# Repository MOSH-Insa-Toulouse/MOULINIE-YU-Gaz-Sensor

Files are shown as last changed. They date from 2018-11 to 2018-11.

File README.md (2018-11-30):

# Connected gas sensor / LoRa TTN
Project 5th ISS - MOSH - TP Gas Sensor
Authors: MOULINIÉ Dorian & YU Juan from INSA Toulouse - 5 ISS

# Description

This main goal of this project is to build a connected nanoparticle gas sensor to monitor the concentration of gas.

For this, we used an Arduino UNO and RN2483 LoRa chip to send data on the The Things Network.

We used Kicad for building this shield. Because it is an Open Source Electronics Design Automation Suite. We are able to use  the Schematic Capture and the PCB Layout along with the 3D Viewer in it. They can help us have a more specific view of our shield.

# Content

a KiCad project manage file

KiCad Schematic files

KiCad PCB Files: A shield for the gas sensor and the LoRa Module to plug in an Arduino Uno

KiCad Libraries

Pictures of the components

Readme file

## Overview

This shield is composed of:

 - a LoRa Module (RN2483) as transceiver
 - a Gas sensor
 - an amplifier (LTC1050)
 - a Groove connector for future calibration of the Gas Sensor

First, we created the project with an arduino UNO

Then, we created a library symbol for LTC 1050

Afterwards, we created the following circuit :
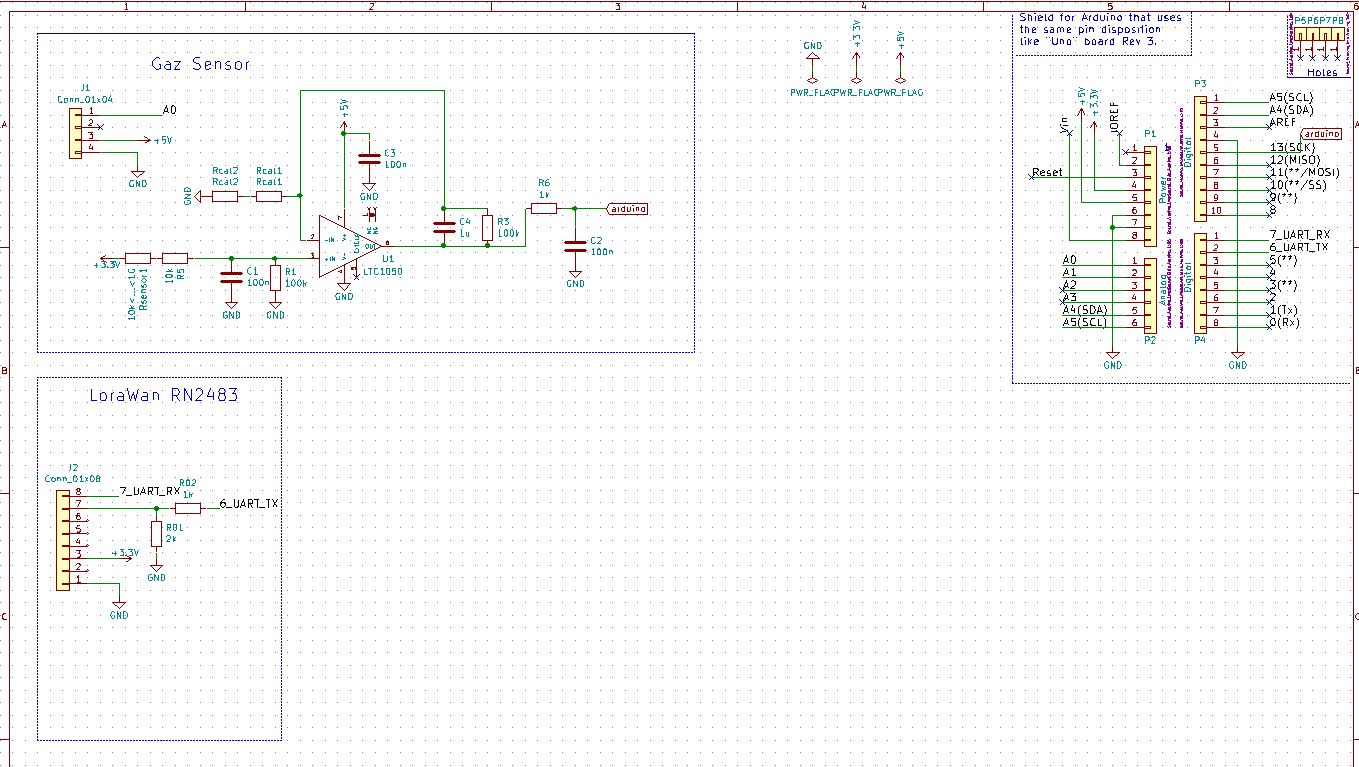
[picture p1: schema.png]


### PCB

In order to add the gas sensor to the board, we first created an new footprint. 

After we had all the components prepared, we started to do the routage.
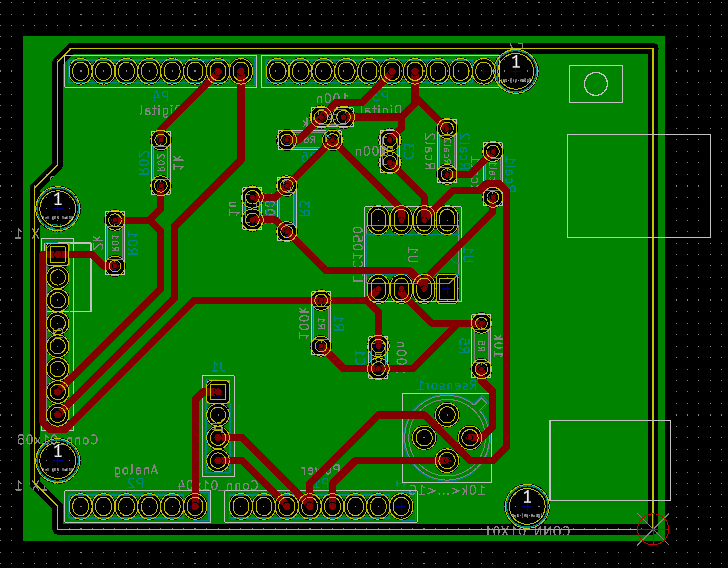
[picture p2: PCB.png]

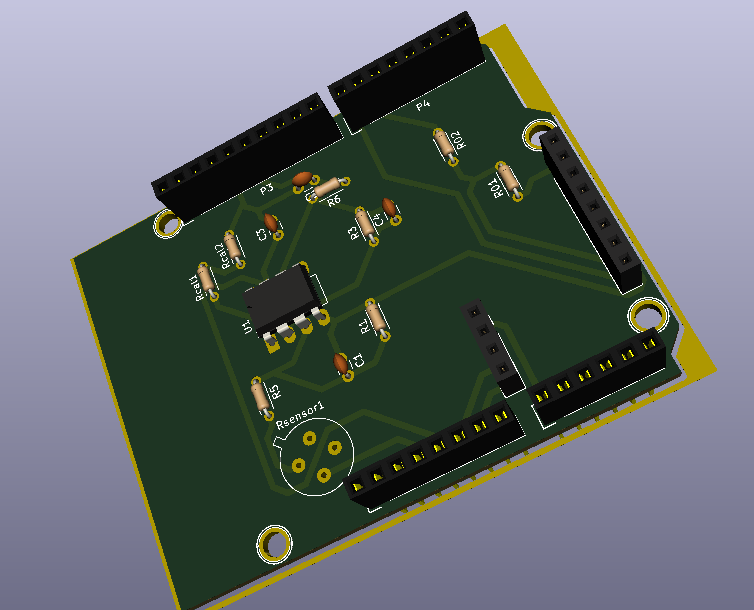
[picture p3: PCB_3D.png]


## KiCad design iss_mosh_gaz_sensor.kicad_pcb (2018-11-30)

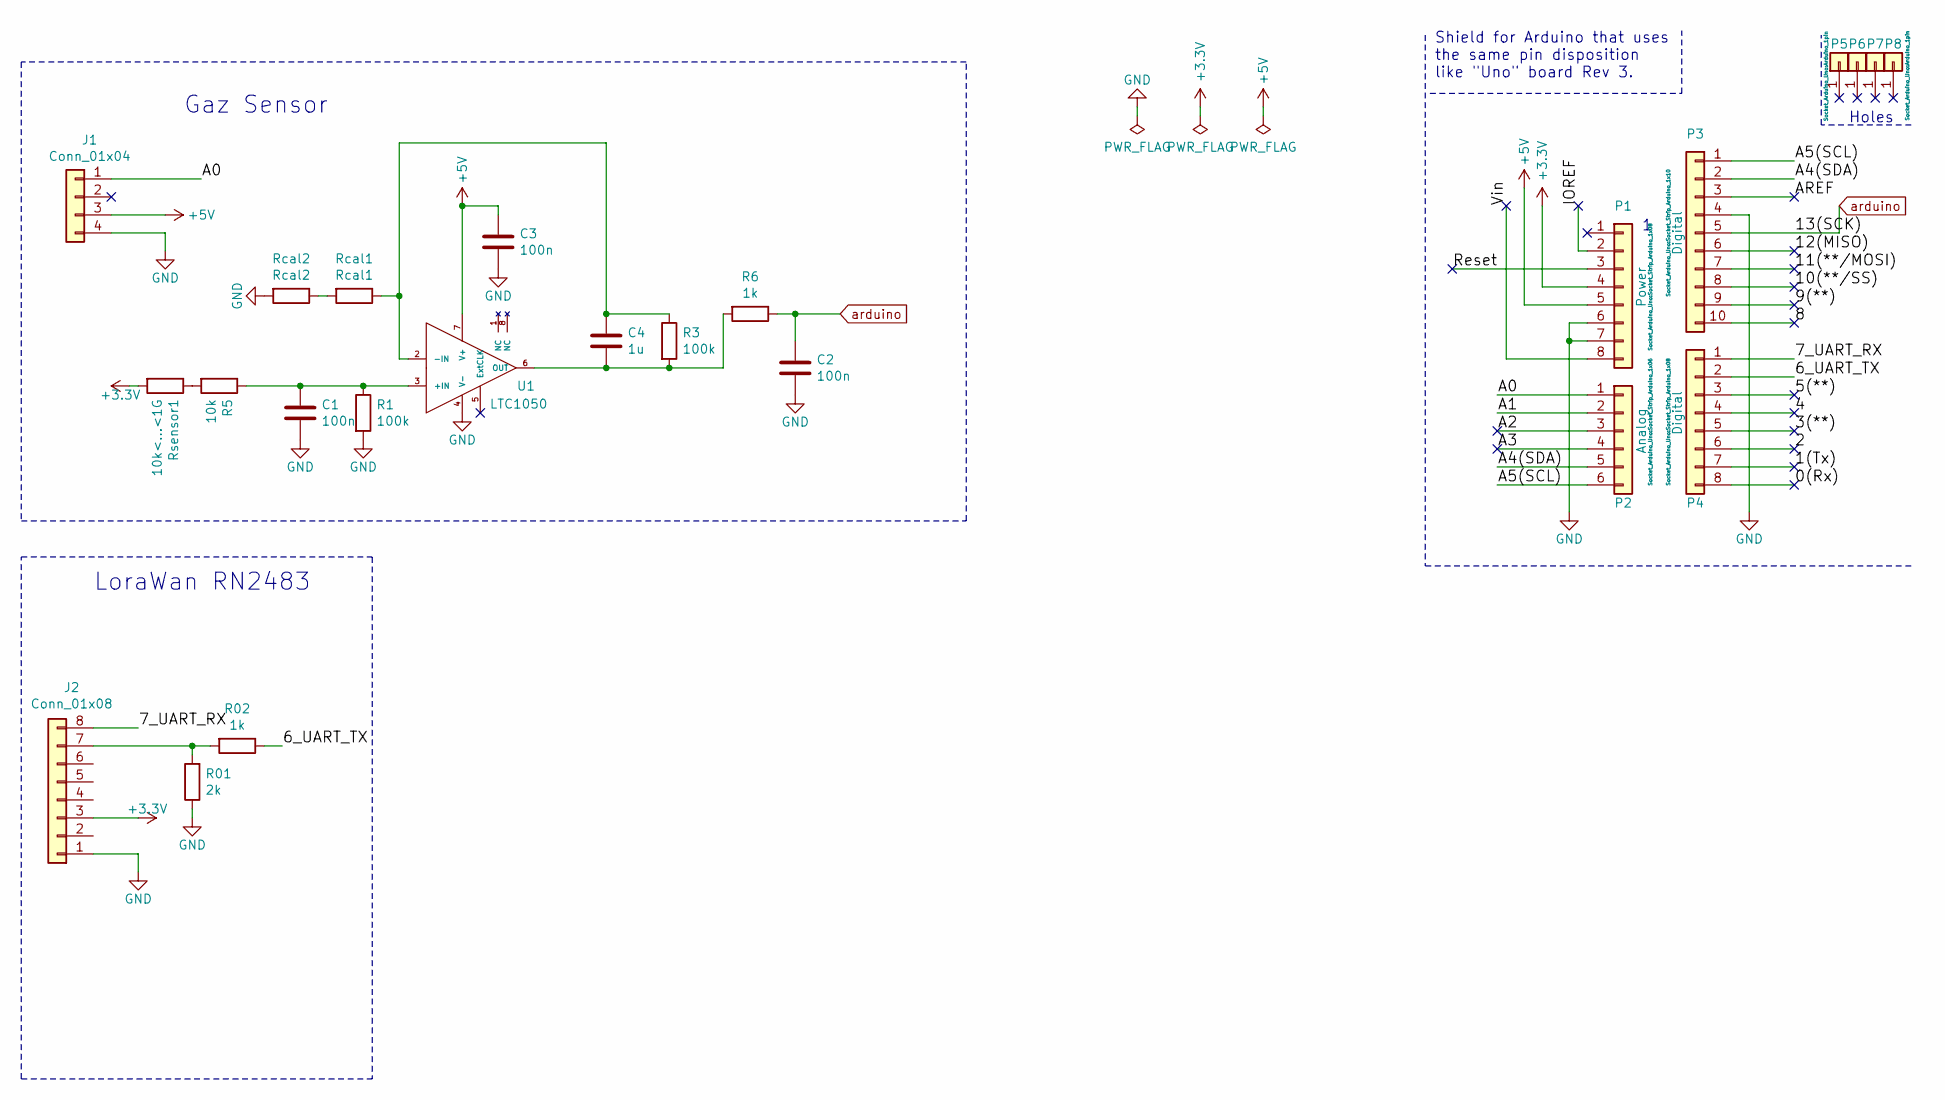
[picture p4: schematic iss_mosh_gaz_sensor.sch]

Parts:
C1, C2, C3: 100n; C_Disc_D3.0mm_W1.6mm_P2.50mm
C4: 1u; C_Disc_D3.0mm_W1.6mm_P2.50mm
J1: Conn_01x04; PinSocket_1x04_P2.54mm_Vertical
J2: Conn_01x08; PinSocket_1x08_P2.54mm_Vertical
P1: Power; Socket_Strip_Arduino_1x08
P2: Analog; Socket_Strip_Arduino_1x06
P3: Digital; Socket_Strip_Arduino_1x10
P4: Digital; Socket_Strip_Arduino_1x08
P5, P6, P7, P8: CONN_01X01; Arduino_1pin
R01: 2k; R_Axial_DIN0204_L3.6mm_D1.6mm_P5.08mm_Horizontal
R1, R3: 100k; R_Axial_DIN0204_L3.6mm_D1.6mm_P5.08mm_Horizontal
R02, R6: 1k; R_Axial_DIN0204_L3.6mm_D1.6mm_P5.08mm_Horizontal
R5: 10k; R_Axial_DIN0204_L3.6mm_D1.6mm_P5.08mm_Horizontal
Rcal1: Rcal1; R_Axial_DIN0204_L3.6mm_D1.6mm_P5.08mm_Horizontal
Rcal2: Rcal2; R_Axial_DIN0204_L3.6mm_D1.6mm_P5.08mm_Horizontal
Rsensor1: 10k<...<1G; TO-5-4(gas_sensor)
U1: LTC1050; DIP-8_W7.62mm_LongPads

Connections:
+3V3: J2.3, P1.4, Rsensor1.2
+5V: C3.1, J1.3, P1.5, U1.7 (V+)
/0(Rx): P4.8
/1(Tx): P4.7
/2: P4.6
/3(**): P4.5
/4: P4.4
/5(**): P4.3
/6_UART_TX: P4.2, R02.1
/7_UART_RX: J2.8, P4.1
/8: P3.10
/9(**): P3.9
/10(**/SS): P3.8
/11(**/MOSI): P3.7
/12(MISO): P3.6
/A0: J1.1, P2.1
/A1: P2.2
/A2: P2.3
/A3: P2.4
/A4(SDA): P2.5, P3.2
/A5(SCL): P2.6, P3.1
/AREF: P3.3
/IOREF: P1.2
/Reset: P1.3
/Vin: P1.8
GND: C1.1, C2.2, C3.2, J1.4, J2.1, P1.6, P1.7, P3.4, R01.1, R1.2, Rcal2.2, U1.4 (V-)
unnamed: C1.2, R1.1, R5.1, U1.3 (+IN)
unnamed: C4.1, R3.1, Rcal1.1, U1.2 (-IN)
unnamed: C4.2, R3.2, R6.2, U1.6 (OUT)
unnamed: J2.7, R01.2, R02.2
unnamed: R5.2, Rsensor1.1
unnamed: Rcal1.2, Rcal2.1
arduino: C2.1, P3.5, R6.1

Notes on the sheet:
Holes
Shield for Arduino that uses the same pin disposition like "Uno" board Rev 3.
Gaz Sensor
LoraWan RN2483

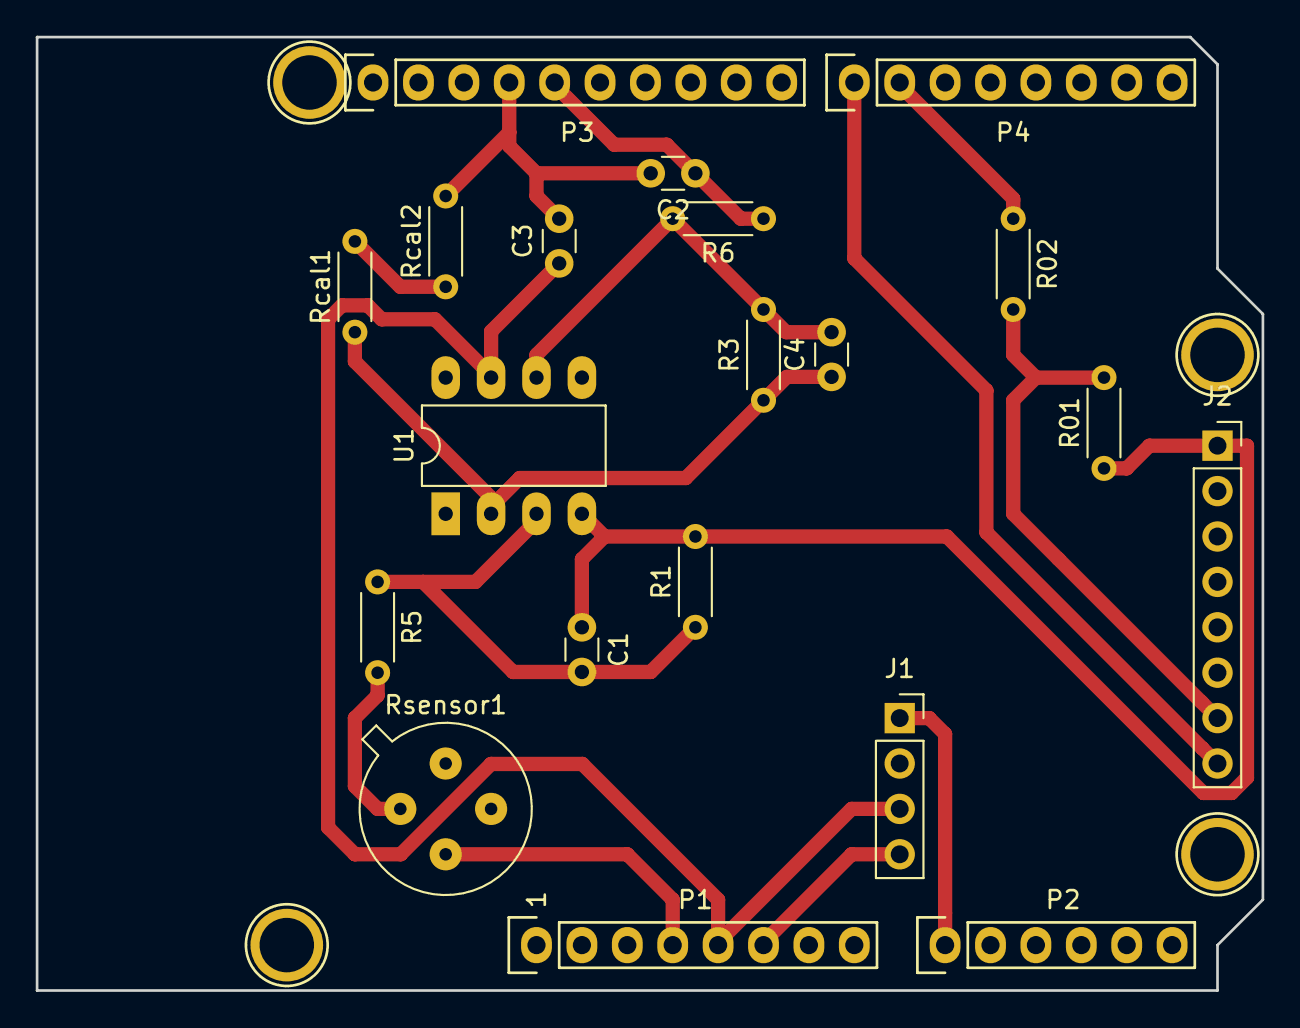
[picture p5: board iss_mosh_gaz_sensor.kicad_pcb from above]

Board: 2 copper layers, 68.6 x 53.3 mm, 24 parts (0 on the bottom side), 15 nets.

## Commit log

2018-10-31 Add LoraWan RN2483 connectic
    [iss_mosh_gaz_sensor.sch]
2018-11-19 add TO5 gas sensor
2018-11-22 add LTC1050
    [_saved_iss_mosh_gaz_sensor.sch]
2018-11-22 gas_sensor_schema
    not all done, half way to success :)
    [_saved_iss_mosh_gaz_sensor.sch, iss_mosh_gaz_sensor.sch]
2018-11-22 gaz sensor(not done)
    [iss_mosh_gaz_sensor.sch]
2018-11-22 name change for R1
    [iss_mosh_gaz_sensor.sch]
2018-11-30 Add footprint of components
    [iss_mosh_gaz_sensor.sch]
